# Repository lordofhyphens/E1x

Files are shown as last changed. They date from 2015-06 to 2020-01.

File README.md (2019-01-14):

# E1x
E1x Printer Files - "V-Slot Lulzbot special"

BOM located here - http://goo.gl/RWq3ZI

Wiki page (with some assembly instructions) - http://reprap.org/wiki/E1x-V

If using the 300x300 Y Carriage for the TAZ and the accompanying borosilicate glass plate, these corner pieces are recommended: 
[Lulzbot Y Corner](http://devel.lulzbot.com/TAZ/Juniper/production_parts/printed_parts/bed_corner/)

Otherwise, edit SCAD/lulz-cornermount to suit the size of your printbed.
The STL is pre-sized for a 12"x12" piece.

This variant employs Vslot on all 3 axes. This arrangement is
experimental, it may take a few re-prints of parts to get things to line up
(particularly the Y axis parts with the printbed).

The X motor and idler endsshould be printed at 0.2mm layer height or lower.  If
using slic3r or another program capable of doing so, use 0.1mm layer heights
between 20.5mm and 21.1mm

With a 300mm bed, the printer is wide enough to home completely off of the bed. 

# Extra Hardware Required
* [6mm Eccentric Spacers](https://openbuildspartstore.com/eccentric-spacer/)
    * 6 required
* [V-Wheels](https://openbuildspartstore.com/solid-v-wheel/)
* [V-Slot Gantry Plate](https://openbuildspartstore.com/v-slot-gantry-plate-universal/)
    * Used for the X Carriage. 
    * Used with [this print](https://www.thingiverse.com/thing:1902194)
* [Aluminum Spacers (6mm thick)](https://openbuildspartstore.com/aluminum-spacers-10-pack/)x10
* T5 or T8 leadscrew with brass or delrin nut
    * T8x8 works, as does T8x2
    * Needs to be around 400mm long
* Either use integrated leadscrews for Z motors (430mm if integrated) or use printed couplers with pipe clamps. 

# Recommended Components
* Use a higher-current NEMA23 motor and external driver for the bed.

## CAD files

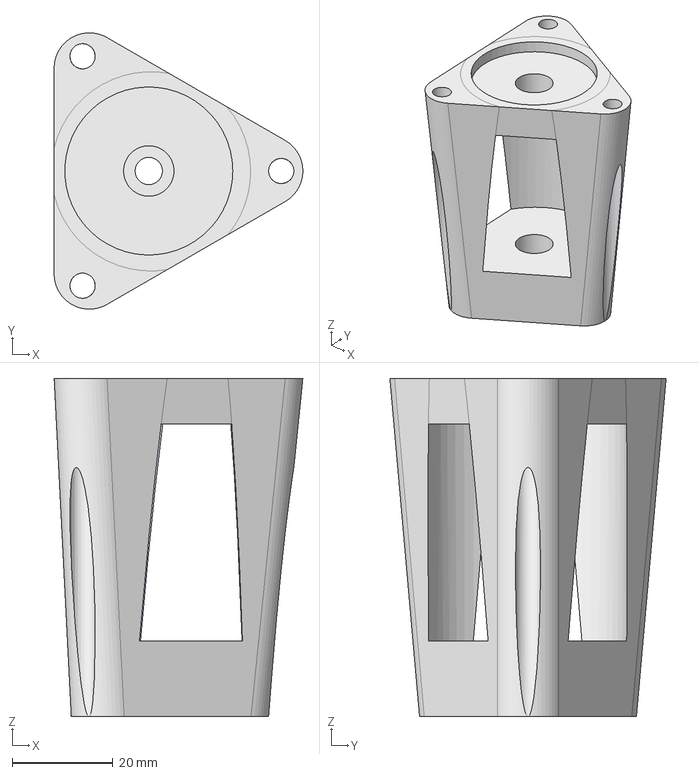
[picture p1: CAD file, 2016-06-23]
FreeCAD/Tri-Foot-1.fcstd
49.3 x 54.8 x 67.0 mm

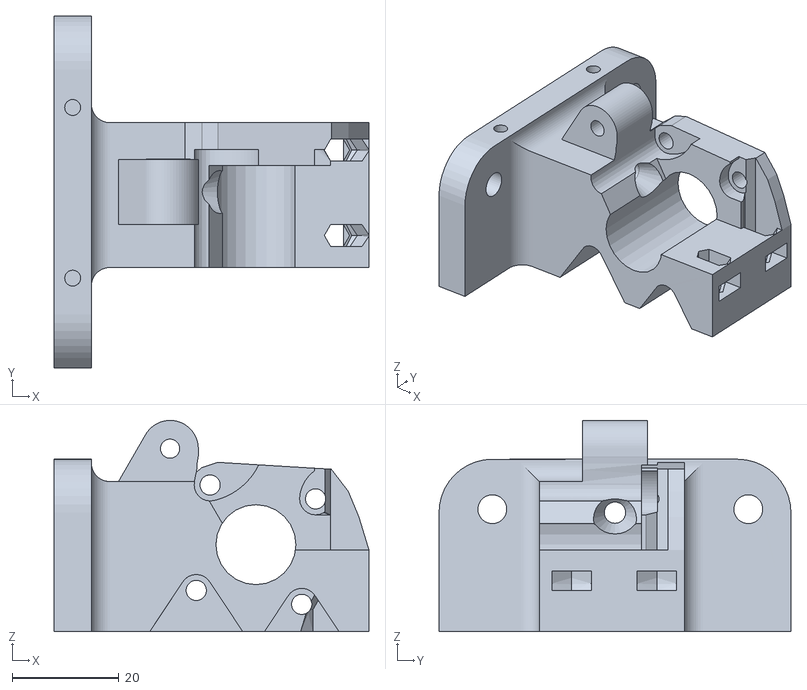
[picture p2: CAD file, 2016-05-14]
SCAD/T1_extruder_v0.9.stl
59.1 x 66.0 x 39.6

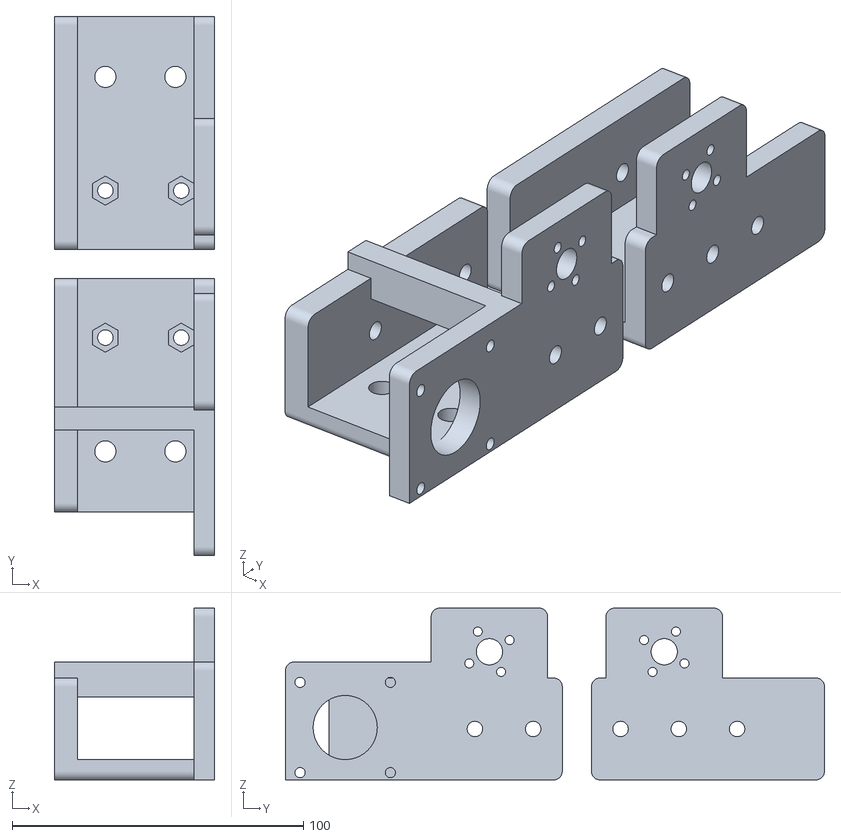
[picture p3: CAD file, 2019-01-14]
STL Files/X_Ends_t8.stl
55.0 x 185.0 x 59.0

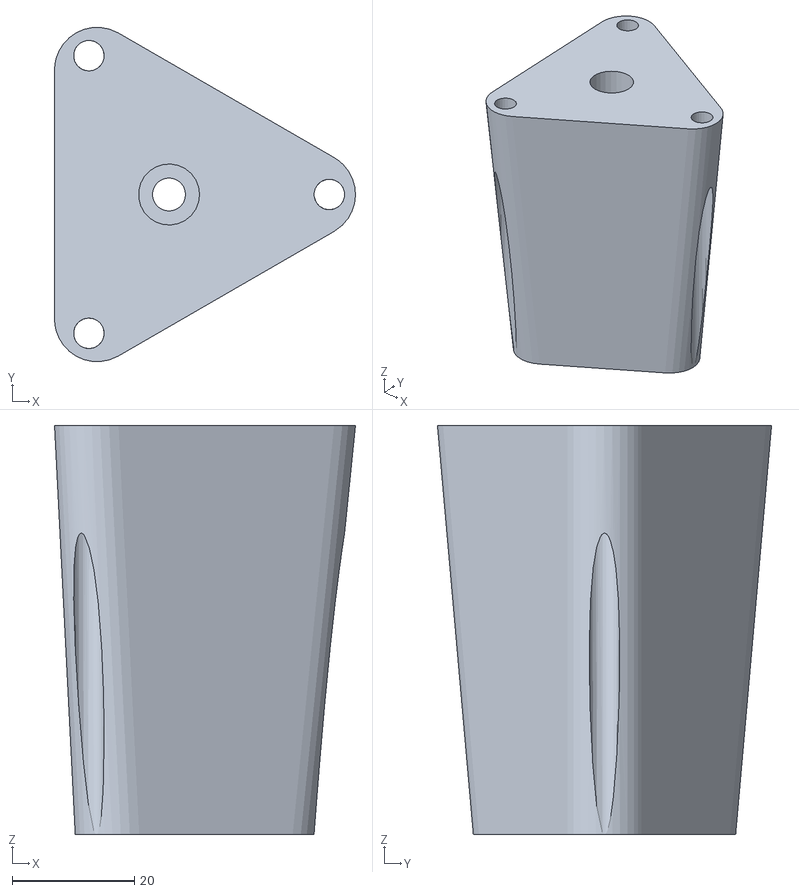
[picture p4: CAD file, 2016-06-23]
STL Files/trifoot.stl
49.3 x 54.7 x 67.0

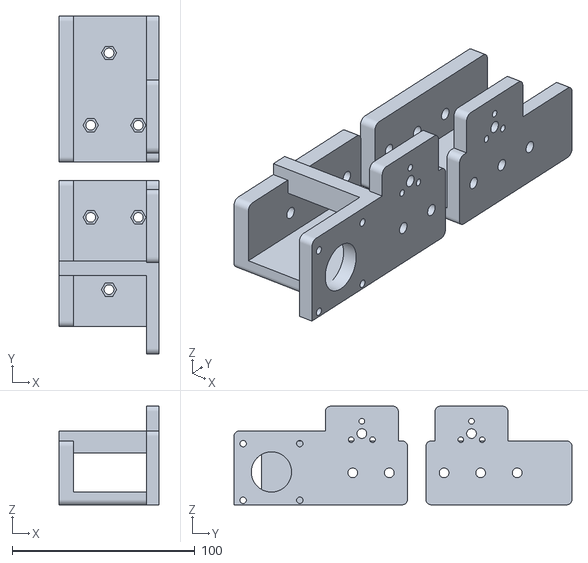
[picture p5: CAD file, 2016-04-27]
STL Files/X_Ends.stl
55.0 x 185.0 x 54.0

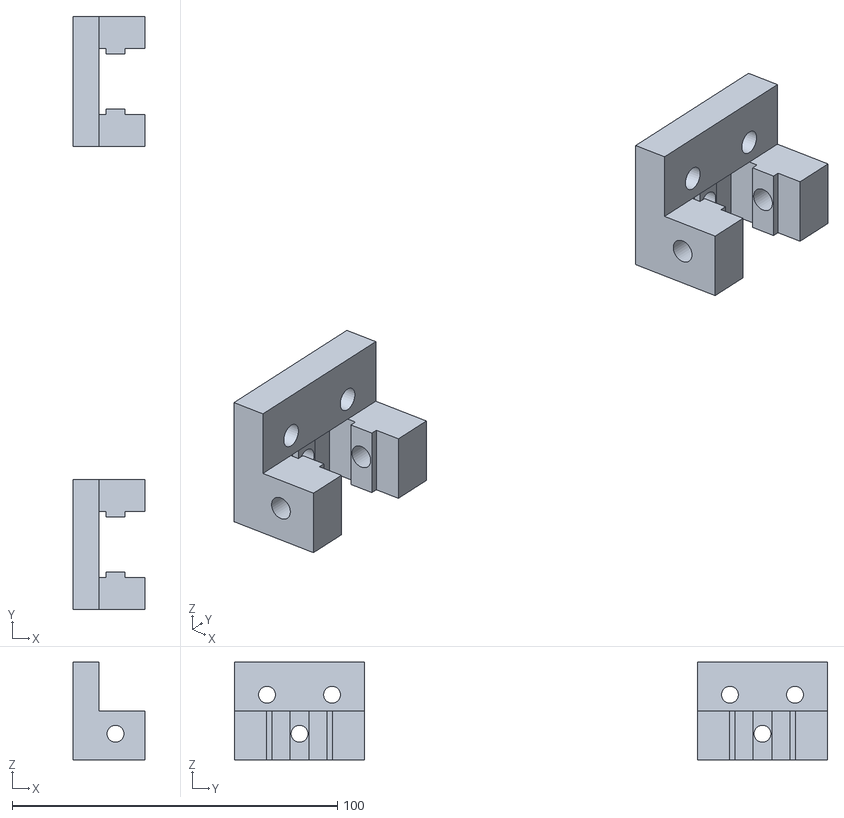
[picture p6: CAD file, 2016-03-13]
STL Files/y-rail-2020.stl
22.0 x 182.3 x 30.0

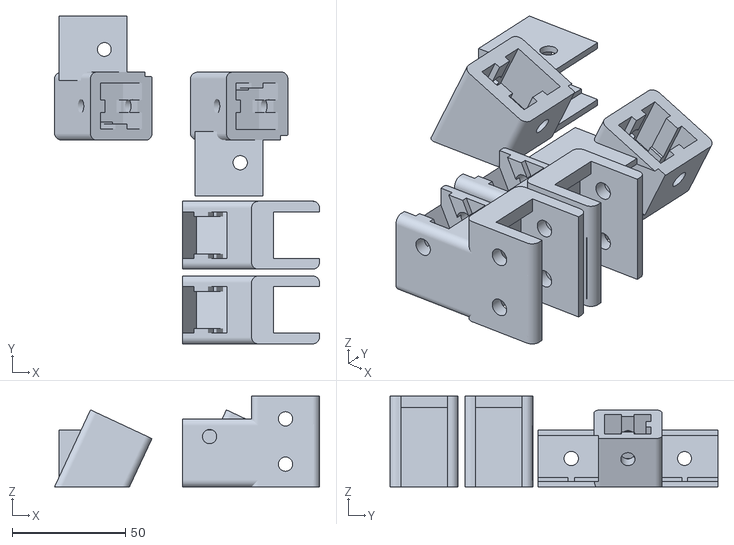
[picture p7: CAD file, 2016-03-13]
STL Files/Y-Triangle_Brackets.stl
117.0 x 144.8 x 40.0

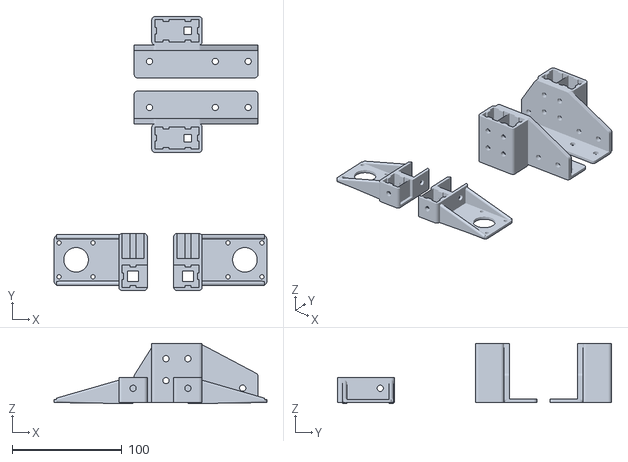
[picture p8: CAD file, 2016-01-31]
STL Files/Z_Axis.stl
194.0 x 250.0 x 55.0

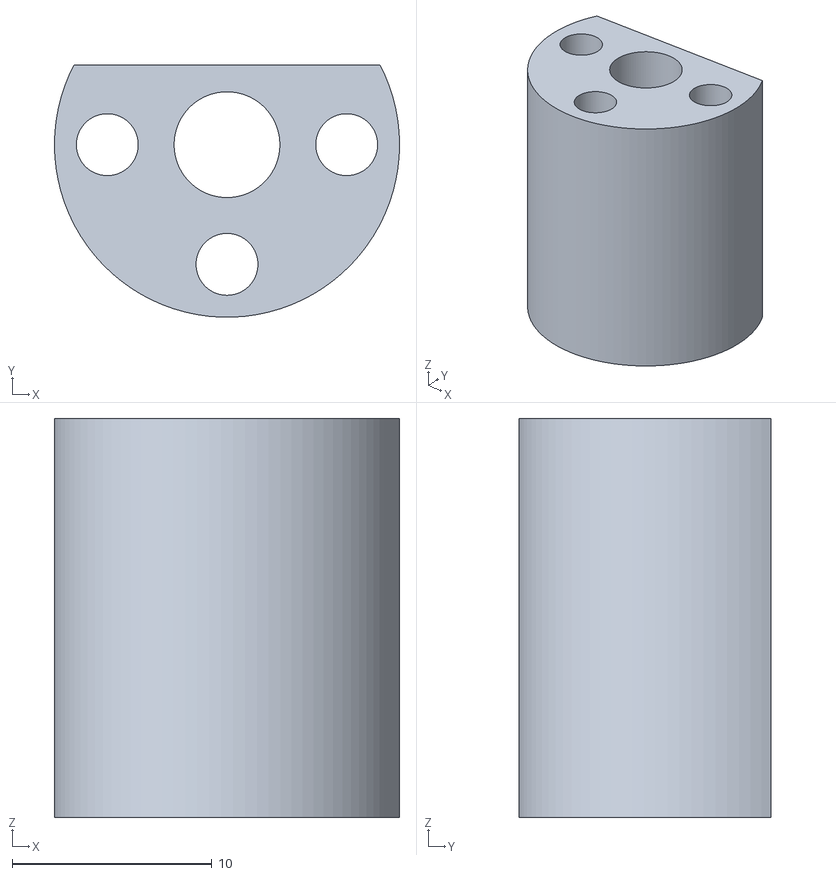
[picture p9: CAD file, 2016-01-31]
STL Files/znut.stl
17.3 x 12.6 x 20.0

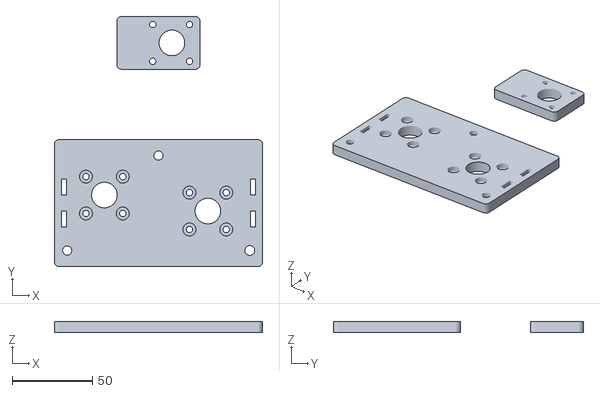
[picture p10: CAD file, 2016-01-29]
STL Files/X_Carriage_2x.stl
130.0 x 156.1 x 7.00

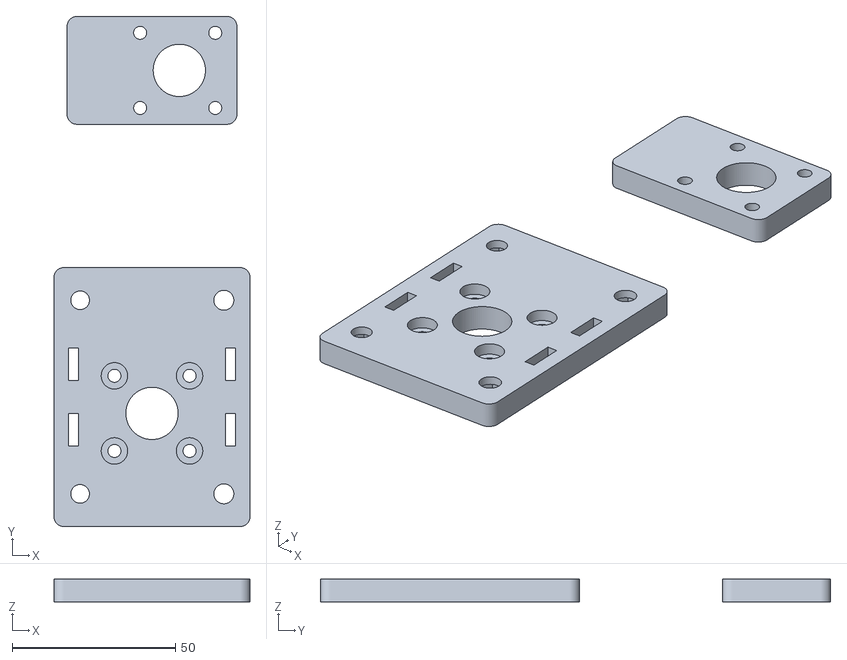
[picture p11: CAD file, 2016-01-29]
STL Files/X_Carriage.stl
60.0 x 156.1 x 7.00

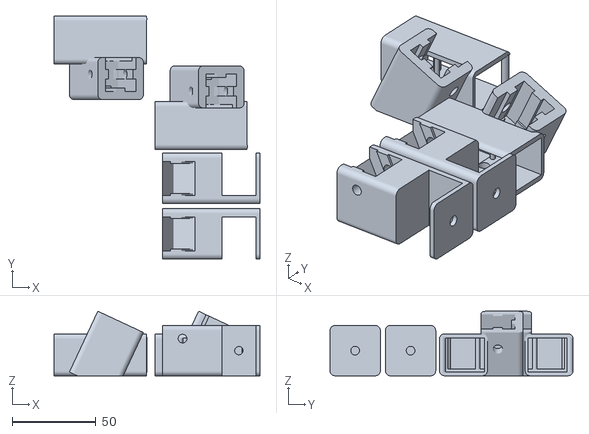
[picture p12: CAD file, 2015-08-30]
STL Files/y-triangle.stl
122.5 x 144.8 x 38.5

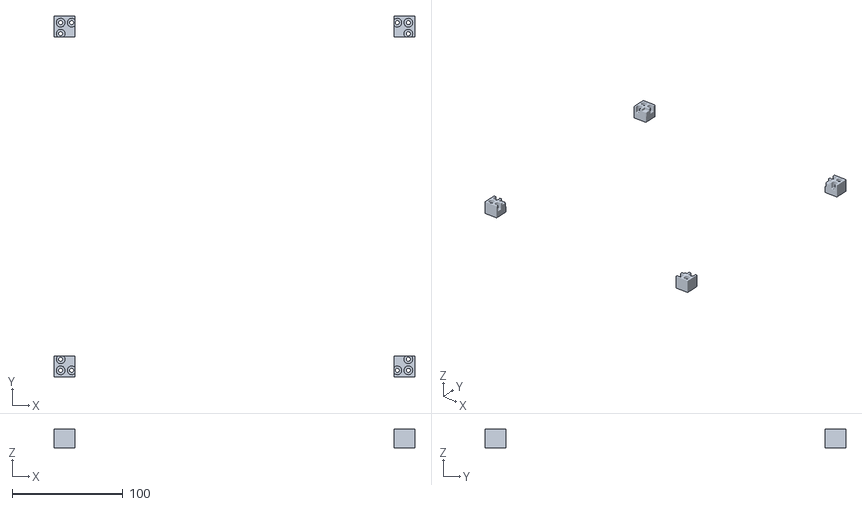
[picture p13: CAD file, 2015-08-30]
STL Files/lulz-cornerbracket.stl
326.0 x 326.0 x 17.0

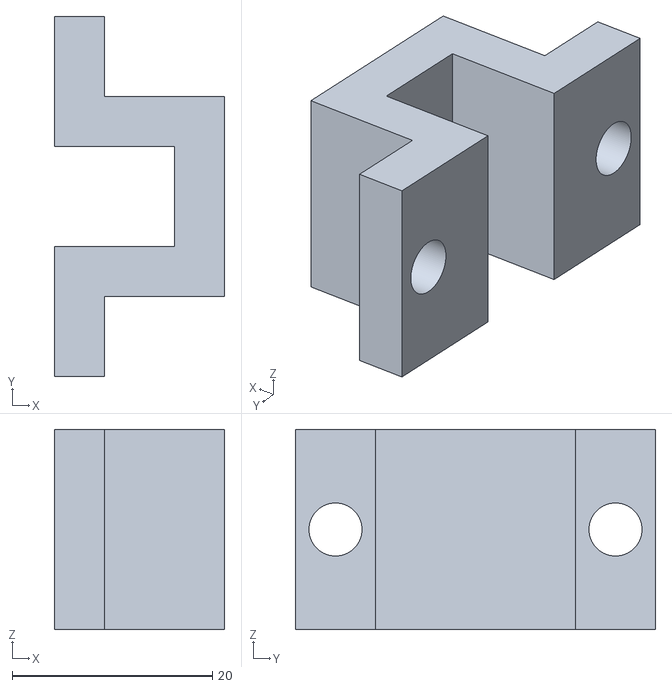
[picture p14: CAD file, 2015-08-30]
STL Files/yIdler_x1.stl
17.0 x 36.0 x 20.0

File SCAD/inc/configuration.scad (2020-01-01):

// Copyright (C) 2012 t00tie
// Adapto is licensed under the Creative Commons - GNU GPL license.
// http://creativecommons.org/licenses/GPL/2.0/

//==========================================================================//
// Configuration file for Adapto OpenSCAD files                             //
// Scroll past the definition section to change basic and advanced settings //
//==========================================================================//

//====================//
// Definition Section //
//====================//
// Frame and Walls
// frameX and frameY are the dimensions of the frame material when viewed on end(the end of an extrusion looks roughly like an X)
// frameX is the width of the frame material
// frameY is the height of the frame material
//   x
//  [ ]y
// these are used to find offsets for screw placing so screws meet the (slot in the) middle of the frame
frameX=20;// width of the frame material(alu, wood etc.)
frameY=20;// height of the frame material

// Print the hole_calibration.scad object to dial in the next 6 settings
// Google found http://www.fairburyfastener.com/xdims_metric_nuts.htm
M8=8.4;// diameter of M8 threaded rod
M5=5.3;// diameter of M5 threaded rod
M3=3.4;// diameter of M3 threaded rod
M8nut=13;// diameter of M8 nut flat to flat
M5nut=8;// diameter of M5 nut flat to flat
M3nut=5.6;// diameter of M3 nut flat to flat

M8nutThickness=6.8;// thickness of a standard M8 nut(nylock is 8mm)
M5nutThickness=4.7;// thickness of a standard M5 nut(nylock is 5mm)
M3nutThickness=2.4;// thickness of a standard M3 nut

// Acme Linear Screw and Nut
ACME14=6.5;// diameter of 1/4 inch ACME threaded rod in mm
ACME14nut=12.8;// diameter of ACME 1/4 inch nut flat to flat in mm
ACME14nutThickness=6.5;// thickness of ACME 1/4 inch nut in mm


// Linear Bearings
// format is IDxODxL
lm8uu=[8, 15, 24];
lm10uu=[10, 19, 29];
lm10luu=[10, 19, 55];
lm12uu=[12, 21, 30];

//rotary bearings
// format is IDxODxL
xx623=[3, 10, 4];
MF204=[4, 10, 4];
MF126=[6, 12, 4];
rotaryBearing=xx623;// for readability(can be changed if other bearings are used

//====================//
// Basic Config Items //
//====================//
smoothRod=8;				// diameter of smooth rods in mm
linearBearing=lm8uu;	// change this to the linear bearing you are using from the definitions section
zRod=M5;				// change this to the z threaded rod you are using from the definitions section
zRodnut=M5nut;		// change this to the z nut you are using from the definitions section
zRodnutThickness=M5nutThickness;	// change this to the z nut thickness you are using from the definitions section


//=======================//
// Advanced Config Items //
//=======================//
$fn=90;		// default resolution for parts, decrease if part compiling or stl/gcode is unmanageable
thickness=5;		// thickness of walls etc. in parts
pullyDiameter=12.2;	// GT2-20 toothed section diameter


offset_from_rail = 25; //(17+6) - 10;
// center of Z drive rod, relative to center of z 2040
shaft_offset=[offset_from_rail+17, 15];
x_rod_thickness=20;
length_to_hole=43;
bearing_to_vslot=9.63;
belt_z_space = 16;
rail_separation = belt_z_space + x_rod_thickness + 2; // minimum space between the top and bottom 
tolerance=1;

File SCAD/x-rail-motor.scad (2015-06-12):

// 48mm separation, center to center
rail_separation = 41;
socket_length = 15;
mass_rotate = [0, 0, 90];
mirrorblock = [1, 0, 0];
trans = [33.5, 0, 0];
difference() {
  union() {
    // positive, brackets 
  translate(trans)
    mirror(mirrorblock) {
    rotate(mass_rotate)
    translate([23.5,38,0.45]) 
      translate([10,20,10])rotate([90,0,0])
          scale([1.05,1.05,1.2])ext2020(l=socket_length, teeth=[0,0,0,0],depth=0);
    rotate(mass_rotate)
    translate([23.5,38,rail_separation-2])  
      translate([10,20,10])rotate([90,0,0])
          scale([1.05,1.0,1.2])ext2020(l=socket_length, teeth=[0,0,0,0],depth=0);
}

    difference(){
      translate([60.5,1.5,0.45]) 
        translate([13,20,-0.5])
        cube([18,24,19+rail_separation]);

      translate([40.5,9.5,0.45]) 
        translate([10,20,15])
        color("blue")cube([90,8,30]);
    }

    // positive, the original idler block
    import("src/X_Axis_Motor_Block_-_1x.stl");
  }
  translate(trans)
  mirror(mirrorblock)
  rotate(mass_rotate)
  {
  translate([23.5,38,0.45]) 
    translate([10,20,10])rotate([90,0,0])
    translate([0,0,-3])ext2020(l=20, teeth=[0,0,0,0]);
  translate([23.5,38,rail_separation+0.45]) 
    translate([10,20,10])rotate([90,0,0])
    translate([0,0,-3])ext2020(l=20, teeth=[0,0,0,1],depth=0);
  translate([23.5,38,-5+0.45]) 
    translate([10,20,10])rotate([90,0,0])
    translate([0,0,-3])ext2020(l=20, teeth=[0,0,0,1],depth=0);
  translate([23.5,39,rail_separation+0.45]) 
    translate([-10,10,10])rotate([90,0,90])
    cylinder(r=m5_diameter/2 + 0.1, h=40, $fs=0.1);
  translate([23.5,39,0.45]) 
    translate([-10,10,10])rotate([90,0,90])
    cylinder(r=m5_diameter/2 + 0.1, h=90, $fs=0.1);
}
}



include <configuration.scad>
include <inc/metric.scad>
use <bushing.scad>
use <inc/bearing-guide.scad>
use <inc/functions.scad>

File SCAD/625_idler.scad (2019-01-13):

module rim(spacer = 2, fender = 2) {
  difference() {
  union() {
  cylinder(d=17, h=fender);
  translate([0,0,fender])
    cylinder(d=8, h=spacer);
  }
  cylinder(d=5.6, h=spacer + fender);
  }
}

module idler_625x2() {
  difference() {
    translate([-2+4,-10,3-2.5+10])cube([33,20,47], center=true);
    translate([15,5,47])
      rotate([90,0,0])
      #cylinder(d=60,h=33);
      translate([1,5,0])
      rotate([90,0,0])

      #ext2020(l=40, teeth=[0,0,1,0]);
      translate([1,5,-19])
      rotate([90,0,0])
      #ext2020(l=40, teeth=[0,0,0,0]);
      translate([1,-10,0])  {
        #cylinder(d=M5, h=45, center=true);
        translate([0,0,20]) 
          #cylinder(d=10, h=15, center=true);
      }
    rotate([0,90,0])
      translate([0,-10,14]) 
      #cylinder(d=M5, h=40, center=true);
  }
  shift = 10;
  _625 = 5.3;
  bearings = 1;
  rim = 4;
  shim = 2;
  wall_thick = 4;
  translate([-20-6,-10,-12+shift]) 
    difference() {
      union(){ 
        for (i = [rim*2+(_625*bearings)+shim*2+2*wall_thick-2, -3])
          translate([10,10,i])
            rotate([90,0,0]) cylinder(d=8,h=20);
        { //lower
          cube([24,20,wall_thick], center=true); 
          translate([0,0,wall_thick*0.5]) cylinder(r1=6, r2=4,h=shim); 
        }
        { // upper
          translate([0,0,wall_thick+shim*2+rim*2+_625*bearings ]) {
            translate([0,0,-wall_thick*0.5-shim]) cylinder(r1=4, r2=6,h=shim);
            cube([24,20,wall_thick], center=true);
          }
        }
      }
      #cylinder(d=M5, h=60, center=true);
    }
}
mirror([0,0,1])
  rotate([90,0,0])idler_625x2();
translate([50,0,0]) rim();
translate([50,20,0]) rim();
include<inc/configuration.scad>
include<inc/functions.scad>
include<inc/extrusions.scad>

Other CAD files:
STL Files/X_Ends_t5.stl
STL Files/trifoot-pocketed.stl
STL Files/Arduino_Flat_Mount.stl
STL Files/Arduino_Corner_Enclosure.stl
SCAD/x-carriage.scad
SCAD/XZ_Assembly.scad
SCAD/X_Carriage.scad
SCAD/X_Ends.scad
SCAD/Z_Axis.scad
SCAD/inc/extrusions.scad
SCAD/inc/functions.scad
SCAD/inc/vslot.scad
SCAD/m5-antibacklash.scad
SCAD/parametric-antibacklash_m5.scad
SCAD/x-rail-idler.scad
SCAD/y-idler-mk2.scad
SCAD/y-rail-2020.scad
SCAD/y-triangle.scad
SCAD/znut.scad
STL Files/Arduino_Cornermount.stl
STL Files/Arduino_Flat_Enclosure.stl
STL Files/M5_Antibacklash_Z_9.5mm_Spring.stl
STL Files/Y_Belt_Holder.stl
STL Files/z_support.stl

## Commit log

2015-05-23 added antibacklash design, inspired by http://www.thingiverse.com/thing:694575
    [M5_Antibacklash_Z_9.5mm_Spring.stl, parametric-antibacklash_m5.scad]
2015-05-23 SCAD was saved as STL.
    [M5_Antibacklash_Z_9.5mm_Spring.stl, m5-antibacklash.scad]
2015-05-24 made the tooth depth configurable.
    Conflicts:
    SCAD/inc/functions.scad
    [functions.scad]
2015-06-09 reduced rail spacing
    [x-carriage.scad, x-rail-idler.scad, x-rail-motor.scad]
2015-06-12 removed side teeth to reduce support needs
    [x-rail-motor.scad]
2015-06-12 updated readme for rail
2015-08-30 added nut bracket and resized for 8mm acme leadscrew
    [Arduino_Corner_Enclosure.stl, Arduino_Cornermount.stl, Arduino_Flat_Enclosure.stl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]
2015-08-30 cleaned up ext2020 to fix how depth and tolerance work
    [functions.scad]
2015-08-30 changed triangle supports to use rounded cubes and added stepping for slots
    [y-triangle.scad, y-triangle.stl]
2016-01-05 change x carriage to resemble something I saw thews did.
    [X_Carriage.scad, X_Carriage.stl]
2016-01-05 some fixes to x carriage
    [X_Carriage.scad, X_Carriage.stl]
2016-01-19 redesigned x ends for a single 2040 rail, with belt in channels
    [X_Ends.scad, configuration.scad, extrusions.scad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]
2016-01-19 shortened X ends
    [X_Ends.scad]
2016-01-19 Changed X carriage to fit on 2040 instead with changed size and mounting method.
    [X_Carriage.scad]
2016-01-19 updated STLs
    [X_Carriage.stl, X_Ends.stl]
2016-01-25 fixed x ends extrusion to use tolerances.
    [X_Ends.scad, extrusions.scad]
2016-01-25 Changed Z to use 2040 vslot instead of 2020. No more smooth rods.
    [X_Ends.scad, X_Ends.stl, Z_Axis.scad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]
2016-01-26 experimental change to use threaded rod and a printed z nut. Should be extensible to brass couplers.
    [X_Ends.scad, X_Ends.stl, znut.scad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]
2016-01-28 Moved the M5 holes for bearings and mounting the 2040.
    [X_Ends.scad]
2016-01-29 Made x carriage a little more modular, added a shifted double X carriage design.
    [X_Carriage.scad, X_Carriage.stl, X_Carriage_2x.stl]
2016-01-29 widened xend stl
    [X_Ends.stl, extrusions.scad]
2016-01-31 simplified axis to move 0,0 to the center of the extrusion
    [X_Ends.scad, Z_Axis.scad, configuration.scad]
2016-01-31 should allow belt path to shift
    [X_Ends.scad, X_Ends.stl, Z_Axis.scad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]
2016-02-17 shifted Z axis upper walls out by a few mm and recentered uppers on rail.
    [Z_Axis.scad]
2016-02-17 Shifted Y triangle brackets to be in-line with z axis and made them easier to print. Reoriented uppers to not wrap completely around and extended their length in Z downwards.
    [Y-Triangle_Brackets.stl, y-triangle.scad]
2016-02-18 tweaked triangle setup
    [y-triangle.scad]
2016-02-20 Changed bracket to be separate pieces again and included cutouts
    [y-rail-2020.scad, y-rail-2020.stl]
2016-03-13 updated x ends
    [X_Ends.scad, X_Ends.stl]
2016-03-30 Reduced material used in X ends and moved to printing orientation.
    [X_Ends.scad, X_Ends.stl, znut.scad]
2016-04-27 updated x carriage to integrate
    [X_Carriage.scad, X_Ends.scad, X_Ends.stl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]
2016-04-27 cut up STL for extruder and added it to x carriage.
    [T1_extruder_v0.9.stl, X_Carriage.scad]
2016-04-28 wrote a better roundcube function for an XY bevel.
    [functions.scad]
2016-05-14 updated roundcube, and using combined x carriage
    [T1_extruder_v0.9.stl, X_Carriage.scad, functions.scad]
2016-06-23 added new printer legs
    [Tri-Foot-1.fcstd, functions.scad, trifoot-pocketed.stl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]
2016-06-23 Revert "wrote a better roundcube function for an XY bevel."
    This reverts commit e760c37d7ba730e57909ae601a22f5a146be5464.
    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
    [X_Carriage.scad]
2016-07-09 lowered idler to use lulzbot parts
    [625_idler.scad, y-idler-mk2.scad]
2019-01-13 Update 2020 to allow for T8 or T5 lead screws, go to 4 slots and support eccentric spacers.
    [625_idler.scad, X_Carriage.scad, X_Ends.scad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]
2019-01-14 Update to use eccentric spacers on 2 wheels for both X ends; removed unnecessary nut traps
    [X_Ends.scad]
2019-01-14 Updated README and STLs for X ends
    [X_Ends_t5.stl, X_Ends_t8.stl]
2020-01-01 add assembly model to show on rail
    [XZ_Assembly.scad]
2020-01-01 realign Z fixed rod, fixed reference to library
    [X_Ends.scad, Z_Axis.scad, configuration.scad]
